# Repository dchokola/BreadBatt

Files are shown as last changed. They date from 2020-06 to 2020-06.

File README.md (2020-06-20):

# BreadBatt
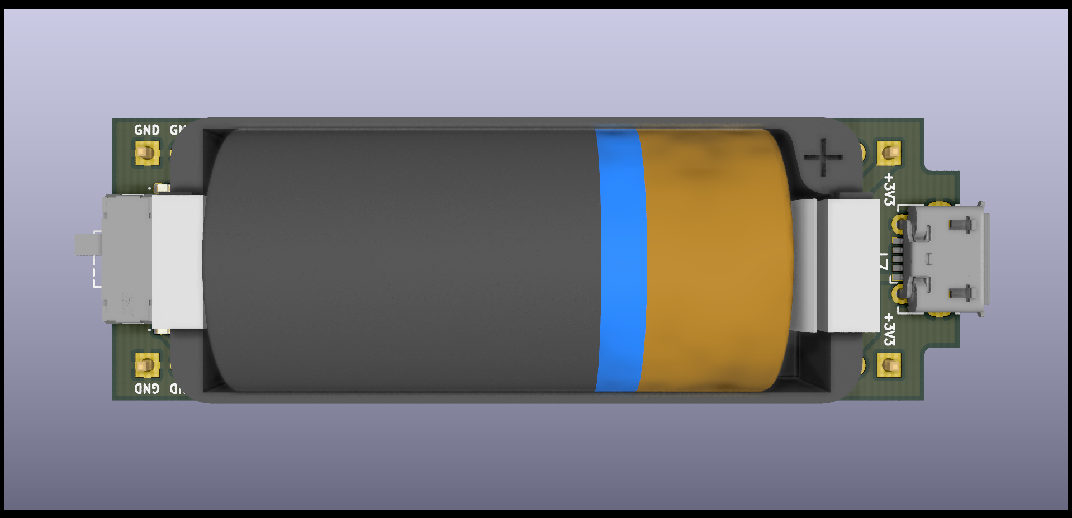
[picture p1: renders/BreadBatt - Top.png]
BreadBatt Top Render

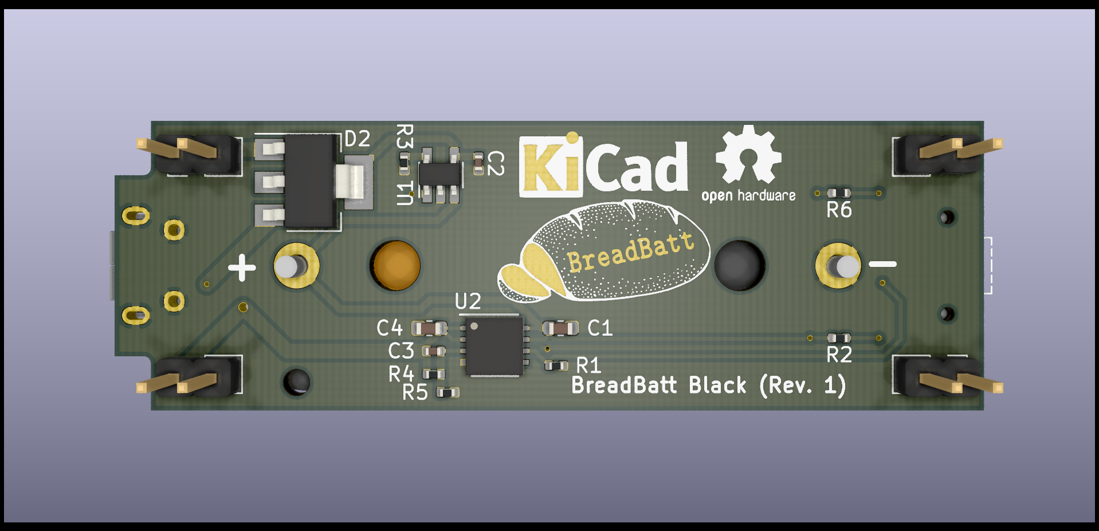
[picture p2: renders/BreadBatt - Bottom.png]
BreadBatt Bottom Render

## What's New in Revision 1
* 100 mils longer profile to let USB overhang the breadboard if needed
* extra pins prevent misalignment
* +5 V USB output pin
* fancy new logo and layout optimized for clear silkscreen on black FR4
* 100% of parts on PCBA now have 3D models
## Features
* uses a single, cheap, easy-to-source 16340 lithium-ion battery
* supplies 3.3 V at up to 2 A
* on/off switch
* on/off and charging LEDs
* built-in thermal and short-circuit protection
* microUSB for charging
* auxilliary +5 V input for charging
* USB +5 V available to breadboard while connected
* silkscreened labels on pins
* open source design with bill of materials

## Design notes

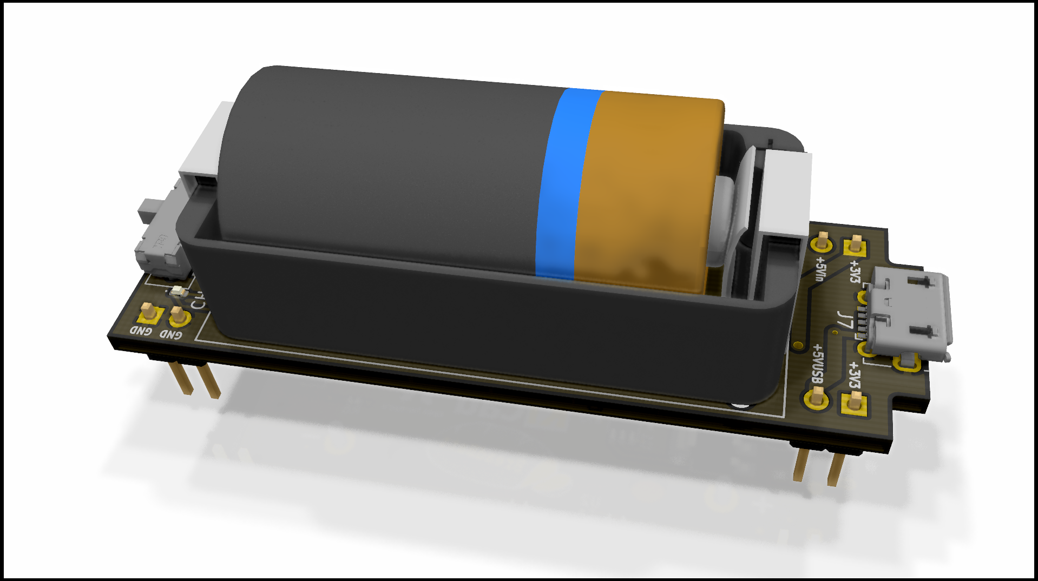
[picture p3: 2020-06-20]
renders/BreadBatt - 3D Profile (Top).png

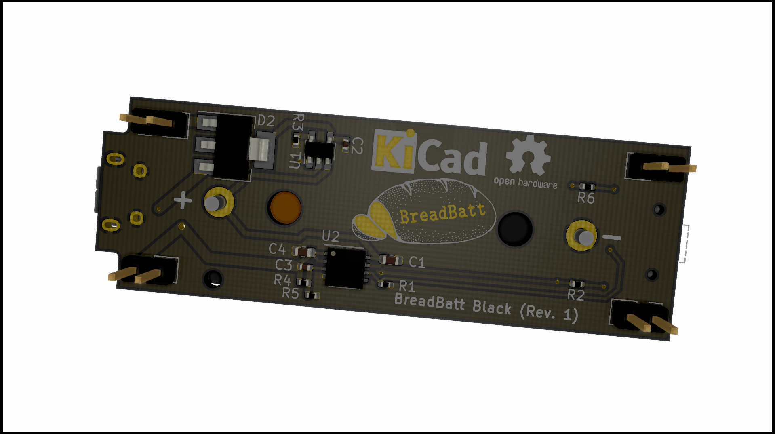
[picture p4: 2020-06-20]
renders/BreadBatt - 3D Profile (Bottom).png

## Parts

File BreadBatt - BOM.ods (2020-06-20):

Reference | Quantity | Value | Manufacturer | Manufacturer Part Number | Vendor | Vendor Part Number
BT1 | 1 | 3.7 V Li-Ion 16340 | Shogyo International Corp. | BHC-CR123A
C1,C4 | 2 | 10u | Samsung Electro-Mechanics | CL10X106MQ8NNNC | Digi-Key | 1276-6827-1-ND
C2 | 1 | 1u | TDK Corporation | CGB2A1X5R1C105K033BC | Digi-Key | 445-13181-1-ND
C3 | 1 | 470n | Samsung Electro-Mechanics | CL05F474ZQ5NNNC | Digi-Key | 1276-1752-1-ND
D1 | 1 | LED, Yellow | Wurth Electronics Inc. | 150040YS73240 | Digi-Key | 732-11993-1-ND
D2 | 1 | BAT120C,115 | Nexperia USA Inc. | BAT120C,115 | Digi-Key | 1727-5450-1-ND
D3 | 1 | LED, Green | Wurth Electronics Inc. | 150040VS73240 | Digi-Key | 732-11992-1-ND
J1,J2 | 2 | +5Vin/GND
J3,J4,J5,J6 | 4 | +3V3/GND
J7 | 1 | Conn_01x05_Shielded | Molex, LLC | 1050170001 | Digi-Key | WM1399CT-ND
R1 | 1 | 100k | Samsung Electro-Mechanics | RC1005F103CS | Digi-Key | 1276-3431-1-ND
R2,R5,R6 | 3 | 1k | Samsung Electro-Mechanics | RC1005F102CS | Digi-Key | 1276-3430-1-ND
R3 | 1 | 1k27 | Panasonic Electronic Components | ERJ-2RKF1271X | Digi-Key | P1.27KLCT-ND
R4 | 1 | 5k6 | Yageo | RC0402JR-075K6L | Digi-Key | 311-5.6KJRCT-ND
SW1 | 1 | SW_SPDT | C&K | JS102011SAQN | Digi-Key | 401-1999-1-ND
U1 | 1 | LTC4054ES5-4.2 | Linear Technology/Analog Devices | LTC4054ES5-4.2#TRMPBF | Digi-Key | LTC4054ES5-4.2#TRMPBFCT-ND
U2 | 1 | LD39200D | STMicroelectronics | LD39200DPUR | Digi-Key | 497-14961-1-ND

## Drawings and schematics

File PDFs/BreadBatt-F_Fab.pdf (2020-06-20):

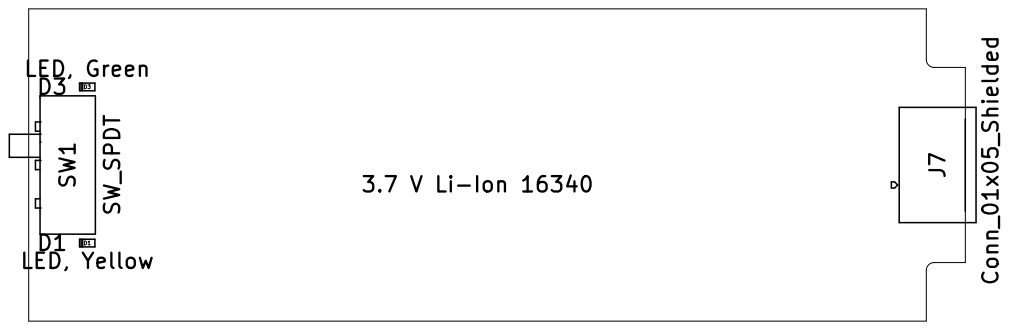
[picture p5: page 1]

3.7 V Li-Ion 16340 D1 LED, Yellow

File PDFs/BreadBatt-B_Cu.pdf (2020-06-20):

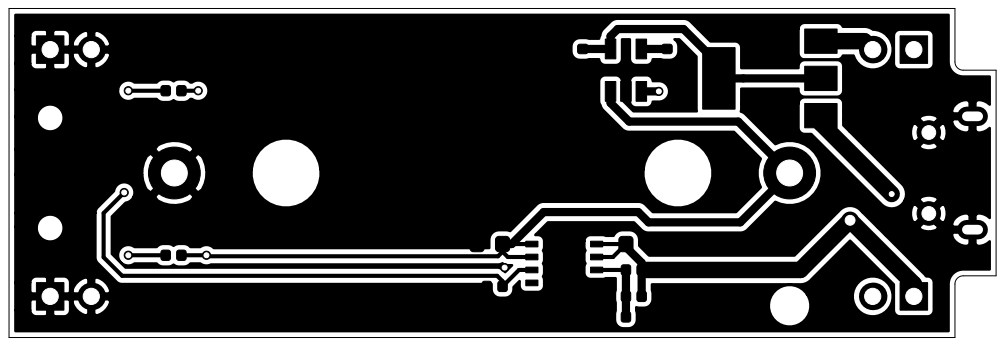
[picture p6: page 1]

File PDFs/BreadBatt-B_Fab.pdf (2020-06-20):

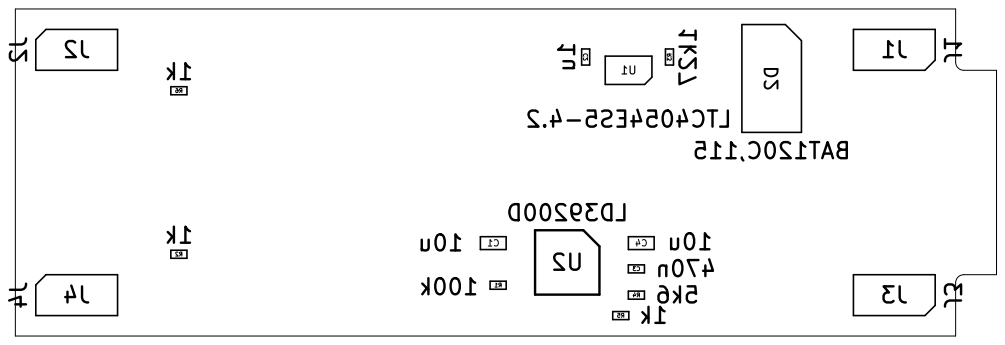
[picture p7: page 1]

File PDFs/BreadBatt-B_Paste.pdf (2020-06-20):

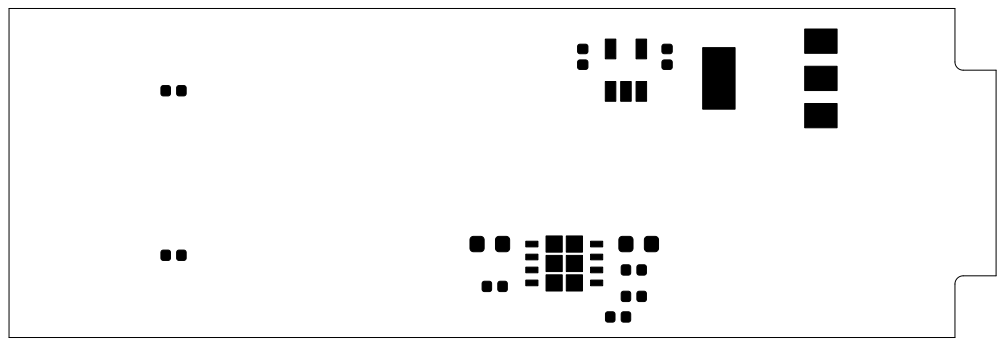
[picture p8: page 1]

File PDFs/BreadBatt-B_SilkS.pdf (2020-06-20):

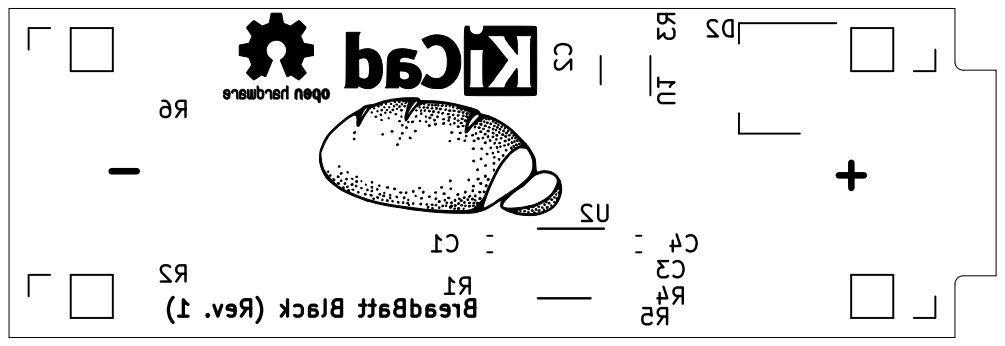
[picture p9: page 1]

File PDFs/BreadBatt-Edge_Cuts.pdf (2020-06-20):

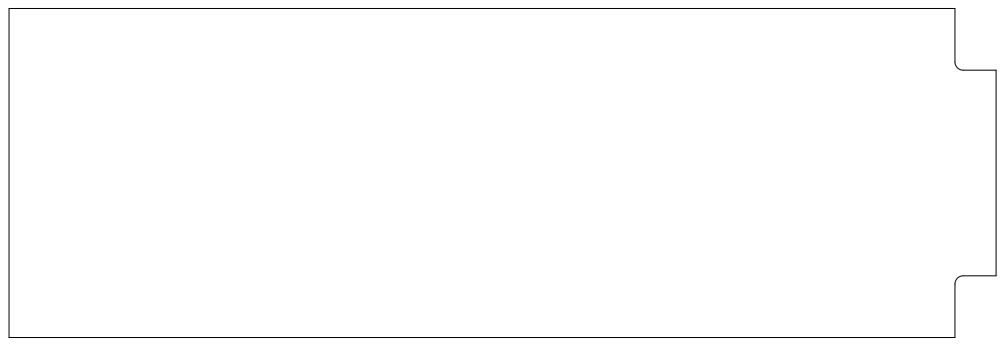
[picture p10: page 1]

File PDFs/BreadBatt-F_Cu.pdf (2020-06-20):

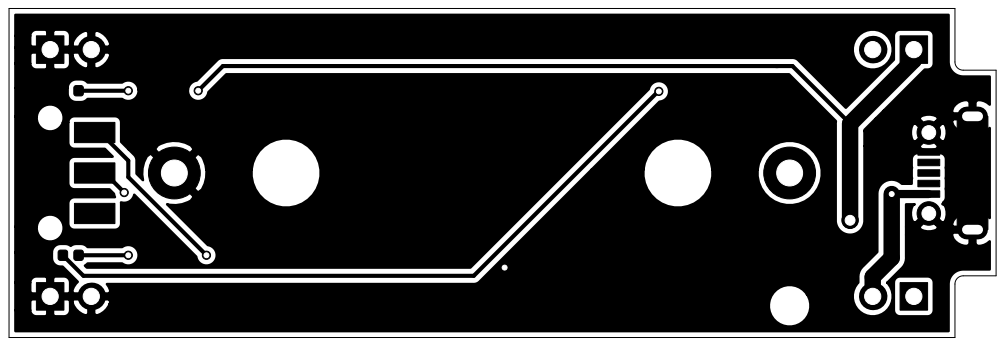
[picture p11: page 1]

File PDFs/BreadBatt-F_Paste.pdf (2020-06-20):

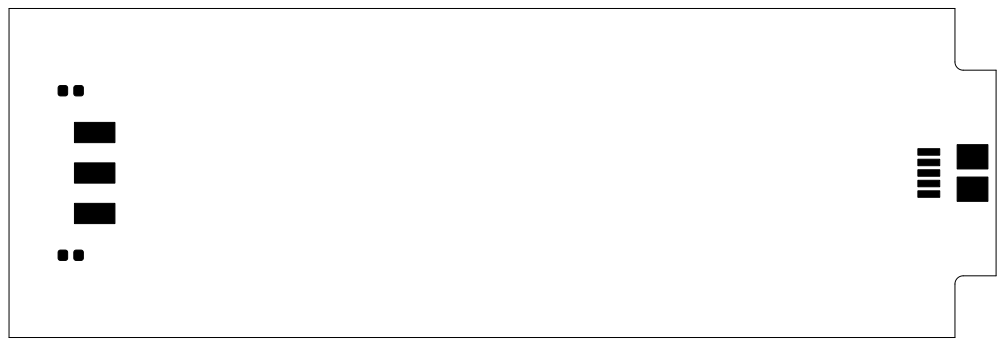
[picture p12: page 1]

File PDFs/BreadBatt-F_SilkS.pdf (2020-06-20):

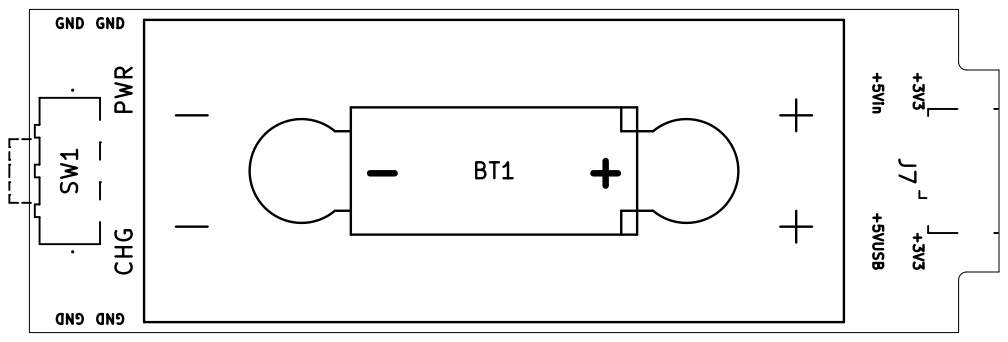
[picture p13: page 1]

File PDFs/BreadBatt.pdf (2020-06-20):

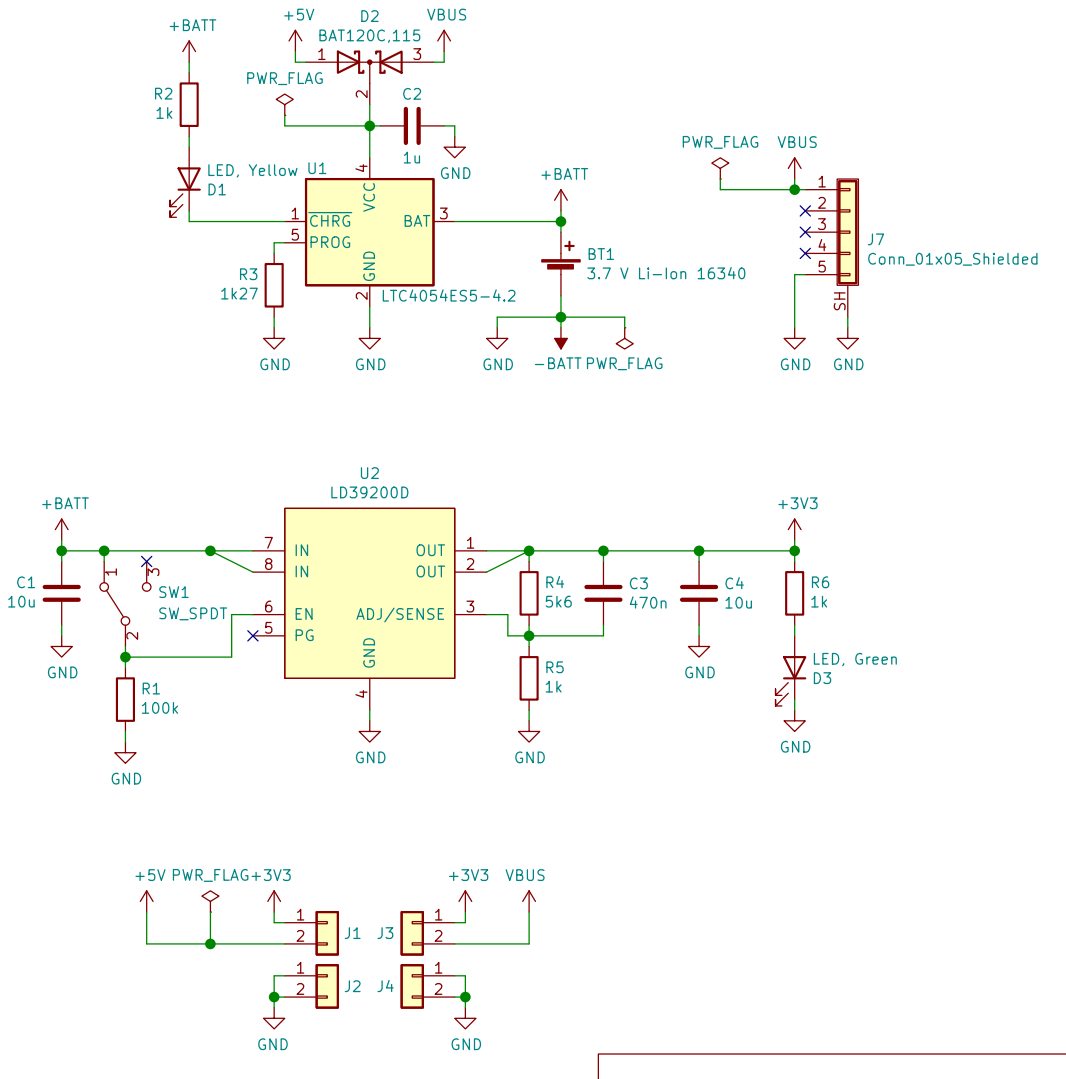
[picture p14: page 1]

Id: 1/1 Title: BreadBatt Black

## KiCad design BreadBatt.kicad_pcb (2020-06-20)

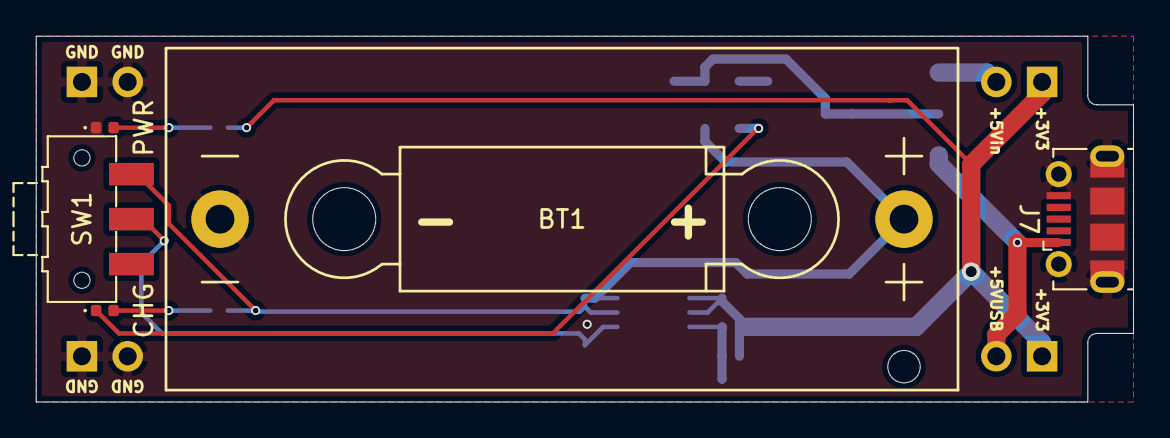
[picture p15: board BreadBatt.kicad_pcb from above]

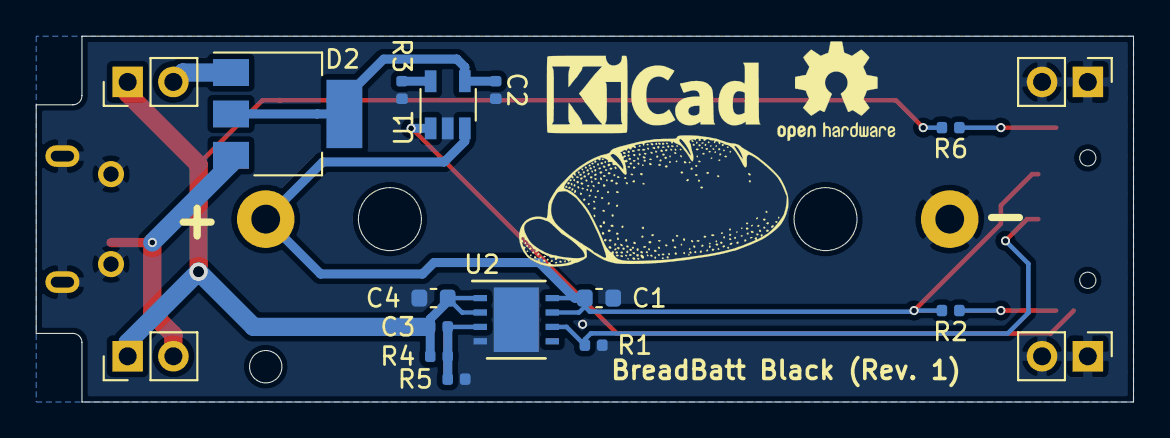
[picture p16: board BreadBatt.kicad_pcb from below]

Board: 2 copper layers, 61.0 x 20.3 mm, 22 parts (17 on the bottom side), 12 nets.

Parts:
BT1: 3.7 V Li-Ion 16340; BHC-CR123A
C1, C4: 10u; C_0603_1608Metric
C2: 1u; C_0402_1005Metric
C3: 470n; C_0402_1005Metric
D1: LED, Yellow; LED_0402_1005Metric
D2: BAT120C,115; SOT-223-3_TabPin2
D3: LED, Green; LED_0402_1005Metric
J1, J2, J3, J4: Conn_01x02; PinHeader_1x02_P2.54mm_Vertical
J7: Conn_01x05_Shielded; USB_Micro-B_Molex-105017-0001
R1: 100k; R_0402_1005Metric
R2, R5, R6: 1k; R_0402_1005Metric
R3: 1k27; R_0402_1005Metric
R4: 5k6; R_0402_1005Metric
SW1: SW_SPDT; SW_SPDT_CK-JS102011SAQN
U1: LTC4054ES5-4.2; TSOT-23-5
U2: LD39200D; DFN-8-1EP_4x4mm_P0.8mm_EP2.5x3.6mm

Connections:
+3V3: C3.1, C4.1, J1.1, J3.1, R4.2, R6.2, U2.1, U2.2
+5V: D2.1, J1.2
+BATT: BT1.1, C1.2, R2.2, SW1.1, U1.3, U2.7, U2.8
-BATT: BT1.2, C1.1, C2.1, C4.2, D3.1, J2.1, J2.2, J4.1, J4.2, J7.5, J7.SH, R1.1, R3.1, R5.1, U1.2, U2.4, U2.9
unnamed: C2.2, D2.2, U1.4
unnamed: C3.2, R4.1, R5.2, U2.3
unnamed: D1.1, U1.1
unnamed: D1.2, R2.1
unnamed: D3.2, R6.1
unnamed: R1.2, SW1.2, U2.6
unnamed: R3.2, U1.5
VBUS: D2.3, J3.2, J7.1

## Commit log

2020-06-20 BreadBatt Revision 0
    [BreadBatt - BOM.csv, BreadBatt - BOM.ods, BreadBatt - BOM.xls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]
2020-06-20 BreadBatt Revision 1
    [BreadBatt - BOM.csv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]
